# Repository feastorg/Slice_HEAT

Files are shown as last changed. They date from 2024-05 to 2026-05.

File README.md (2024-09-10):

# DC heating Element Controller Slice

DC heating Element Controller Slice for BREAD.

## Introduction

[Short introduction on the project.]

## Usage

[Explain how to use the project. Include examples and screenshots if applicable.]

## Documentation

Please refer to the [docs](/docs) for more info.

---

<div align="center">
  <p>
    
    
  </p>
</div>

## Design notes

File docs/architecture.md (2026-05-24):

---
title: "Architecture"
description: "Hardware and firmware architecture overview."
---

# Architecture

## Hardware

Heater control slice with MAX31855K thermocouple interface for closed-loop temperature control.

## Firmware

Arduino-based heater control sketch (`HEAT.ino`).

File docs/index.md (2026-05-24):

---
title: "Slice HEAT Documentation"
description: "Overview and entry page for Slice HEAT project documentation."
nav_exclude: true
---

Welcome to the Slice HEAT project documentation.

## Board Renders

<figure style="display:inline-block; text-align:center; margin:10px;">
  Board Top
  <figcaption>Top</figcaption>
</figure>

<figure style="display:inline-block; text-align:center; margin:10px;">
  Board Bottom
  <figcaption>Bottom</figcaption>
</figure>

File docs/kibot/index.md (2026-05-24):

---
title: "KiBot Outputs"
description: "Index for KiBot-generated PCB artifacts."
layout: "page"
---

These are the docs & KiBot Outputs for Slice HEAT

The following files were generated from the latest PCB build:

_(Not yet generated — will be populated by CI on first successful run.)_

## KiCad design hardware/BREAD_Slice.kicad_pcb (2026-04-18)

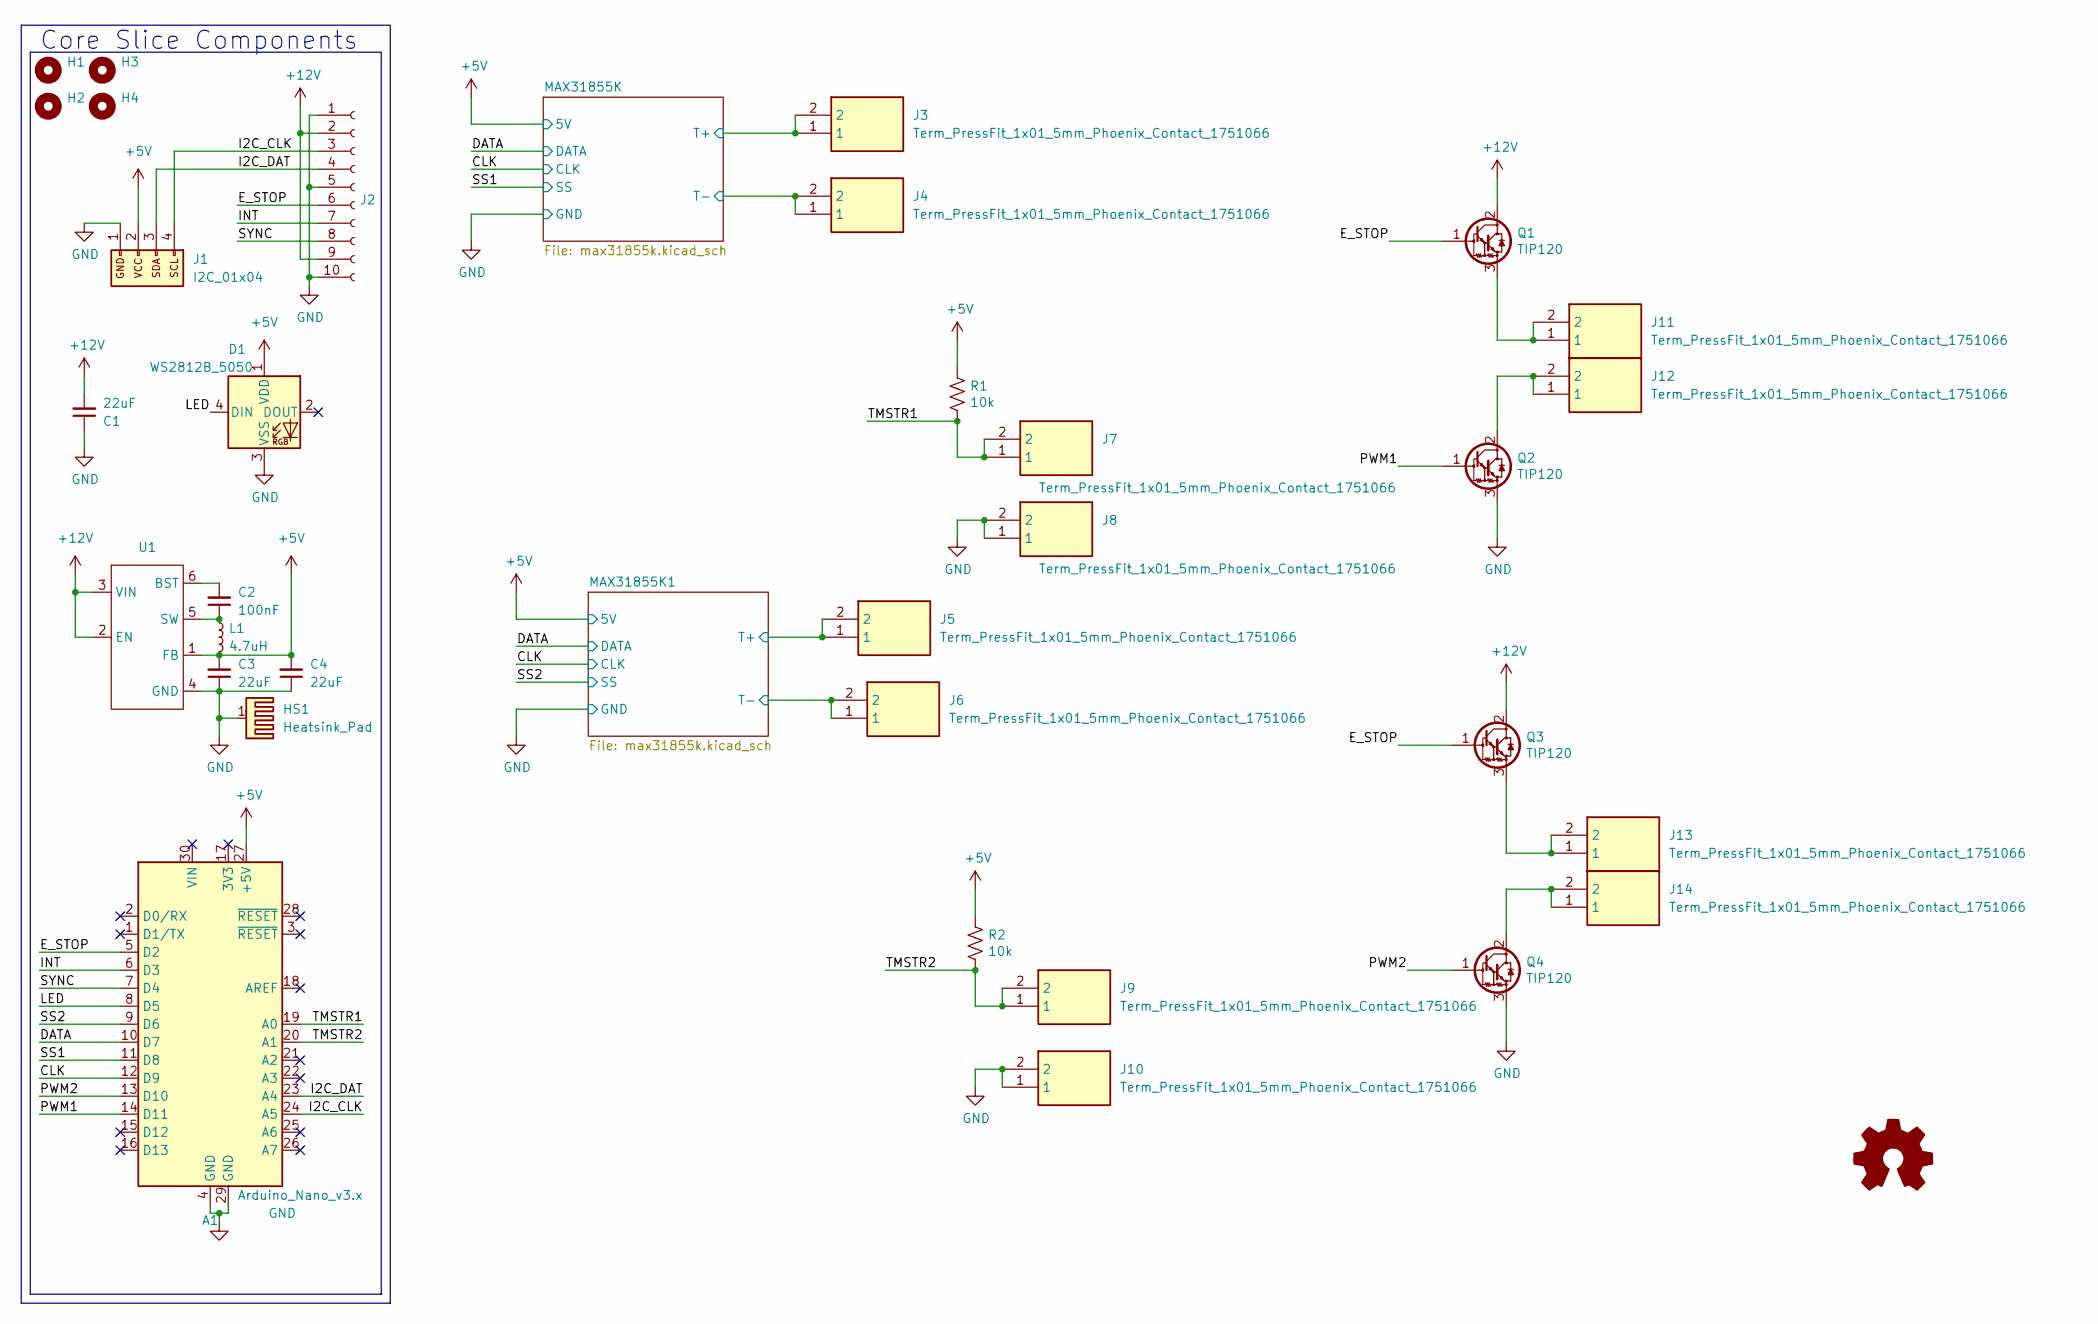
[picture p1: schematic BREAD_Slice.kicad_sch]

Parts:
A1: Arduino_Nano_v3.x; Arduino_Nano
C1, C3, C4: 22uF; C_1206_3216Metric
C2: 100nF; C_1206_3216Metric
D1: WS2812B_5050; WS2812-5050-4PIN
H1, H2, H3, H4: MountingHole; MountingHole_5mm
HS1: Heatsink_Pad; Thermal Pad
J1: I2C_01x04; JST_SH_SM04B-SRSS-TB_1x04-1MP_P1.00mm_Horizontal
J2: Conn_01x10_Female; PinSocket_1x10_P2.54mm_Horizontal
J3, J4, J5, J6, J7, J8, J9, J10, J11, J12, J13, J14: Term_PressFit_1x01_5mm_Phoenix_Contact_1751066; 1751066; Manufacturer_Part_Number 1751066
L1: 4.7uH; L_1210_3225Metric
Q1, Q2: TIP120; TO-220-3_Horizontal_TabDown
Q3, Q4: TIP120; TO-220-3_Horizontal_TabUp
R1, R2: 10k; R_1206_3216Metric_Pad1.30x1.75mm_HandSolder
U1: TSOT-23-6

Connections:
+5V: A1.27 (+5V), C3.2, C4.2, D1.1 (VDD), J1.2, L1.2, R1.1, R2.1, U1.1 (FB); also elsewhere on the board
+12V: C1.2, J2.2, J2.9, Q1.2 (C), Q3.2 (C), U1.2 (EN), U1.3 (VIN)
/CLK: A1.12 (D9); also elsewhere on the board
/DATA: A1.10 (D7); also elsewhere on the board
/E_STOP: A1.5 (D2), J2.6, Q1.1 (B), Q3.1 (B)
/I2C_CLK: A1.24 (A5), J1.4, J2.3
/I2C_DAT: A1.23 (A4), J1.3, J2.4
/INT: A1.6 (D3), J2.7
/LED: A1.8 (D5), D1.4 (DIN)
/MAX31855K1/T+: J5.1, J5.2; also elsewhere on the board
/MAX31855K1/T-: J6.1, J6.2; also elsewhere on the board
/MAX31855K/T+: J3.1, J3.2; also elsewhere on the board
/MAX31855K/T-: J4.1, J4.2; also elsewhere on the board
/PWM1: A1.14 (D11), Q2.1 (B)
/PWM2: A1.13 (D10), Q4.1 (B)
/SS1: A1.11 (D8); also elsewhere on the board
/SS2: A1.9 (D6); also elsewhere on the board
/SYNC: A1.7 (D4), J2.8
/TMSTR1: A1.19 (A0), J7.1, J7.2, R1.2
/TMSTR2: A1.20 (A1), J9.1, J9.2, R2.2
GND: A1.4 (GND), A1.29 (GND), C1.1, C3.1, C4.1, D1.3 (VSS), HS1.1, J1.1, J2.1, J2.5, J2.10, J8.1, J8.2, J10.1, J10.2, Q2.3 (E), Q4.3 (E), U1.4 (GND); also elsewhere on the board
unnamed: J11.1, J11.2, Q1.3 (E)
unnamed: J12.1, J12.2, Q2.2 (C)
unnamed: J13.1, J13.2, Q3.3 (E)
unnamed: J14.1, J14.2, Q4.2 (C)
unnamed: C2.2, U1.6 (BST)
unnamed: C2.1, L1.1, U1.5 (SW)

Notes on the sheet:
Core Slice Components

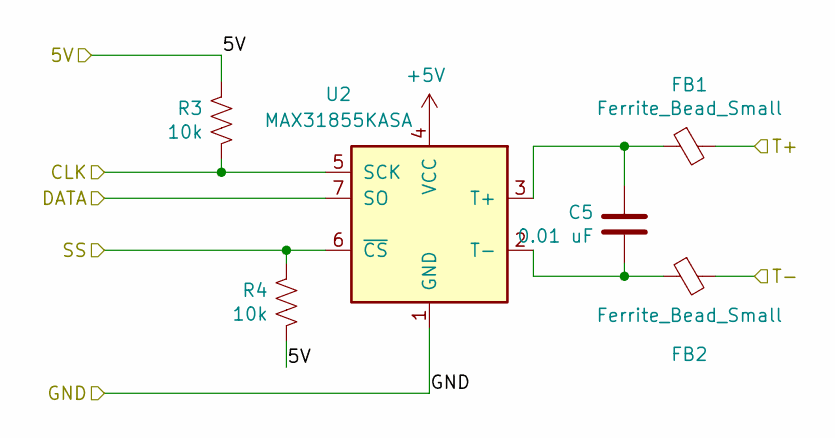
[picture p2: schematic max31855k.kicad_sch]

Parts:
C5: 0.01 uF; C_1206_3216Metric_Pad1.33x1.80mm_HandSolder
FB1, FB2: Ferrite_Bead_Small; R_1206_3216Metric_Pad1.30x1.75mm_HandSolder
R3, R4: 10k; R_1206_3216Metric_Pad1.30x1.75mm_HandSolder
U2: MAX31855KASA; SOIC-8_3.9x4.9mm_P1.27mm

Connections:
+5V: R3.1, R4.2, U2.4 (VCC); also elsewhere on the board
/CLK: R3.2, U2.5 (SCK); also elsewhere on the board
/DATA: U2.7 (SO); also elsewhere on the board
/MAX31855K/T+: FB1.2; also elsewhere on the board
/MAX31855K/T-: FB2.2; also elsewhere on the board
/SS1: R4.1, U2.6 (~CS); also elsewhere on the board
GND: U2.1 (GND); also elsewhere on the board
unnamed: C5.1, FB1.1, U2.3 (T+)
unnamed: C5.2, FB2.1, U2.2 (T-)

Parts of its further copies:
C6: 0.01 uF; C_1206_3216Metric_Pad1.33x1.80mm_HandSolder
FB3, FB4: Ferrite_Bead_Small; R_1206_3216Metric_Pad1.30x1.75mm_HandSolder
R5, R6: 10k; R_1206_3216Metric_Pad1.30x1.75mm_HandSolder
U3: MAX31855KASA; SOIC-8_3.9x4.9mm_P1.27mm

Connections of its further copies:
+5V: R5.1, R6.2, U3.4 (VCC); also elsewhere on the board
/CLK: R5.2, U3.5 (SCK); also elsewhere on the board
/DATA: U3.7 (SO); also elsewhere on the board
/MAX31855K1/T+: FB3.2; also elsewhere on the board
/MAX31855K1/T-: FB4.2; also elsewhere on the board
/SS2: R6.1, U3.6 (~CS); also elsewhere on the board
GND: U3.1 (GND); also elsewhere on the board
unnamed: C6.1, FB3.1, U3.3 (T+)
unnamed: C6.2, FB4.1, U3.2 (T-)

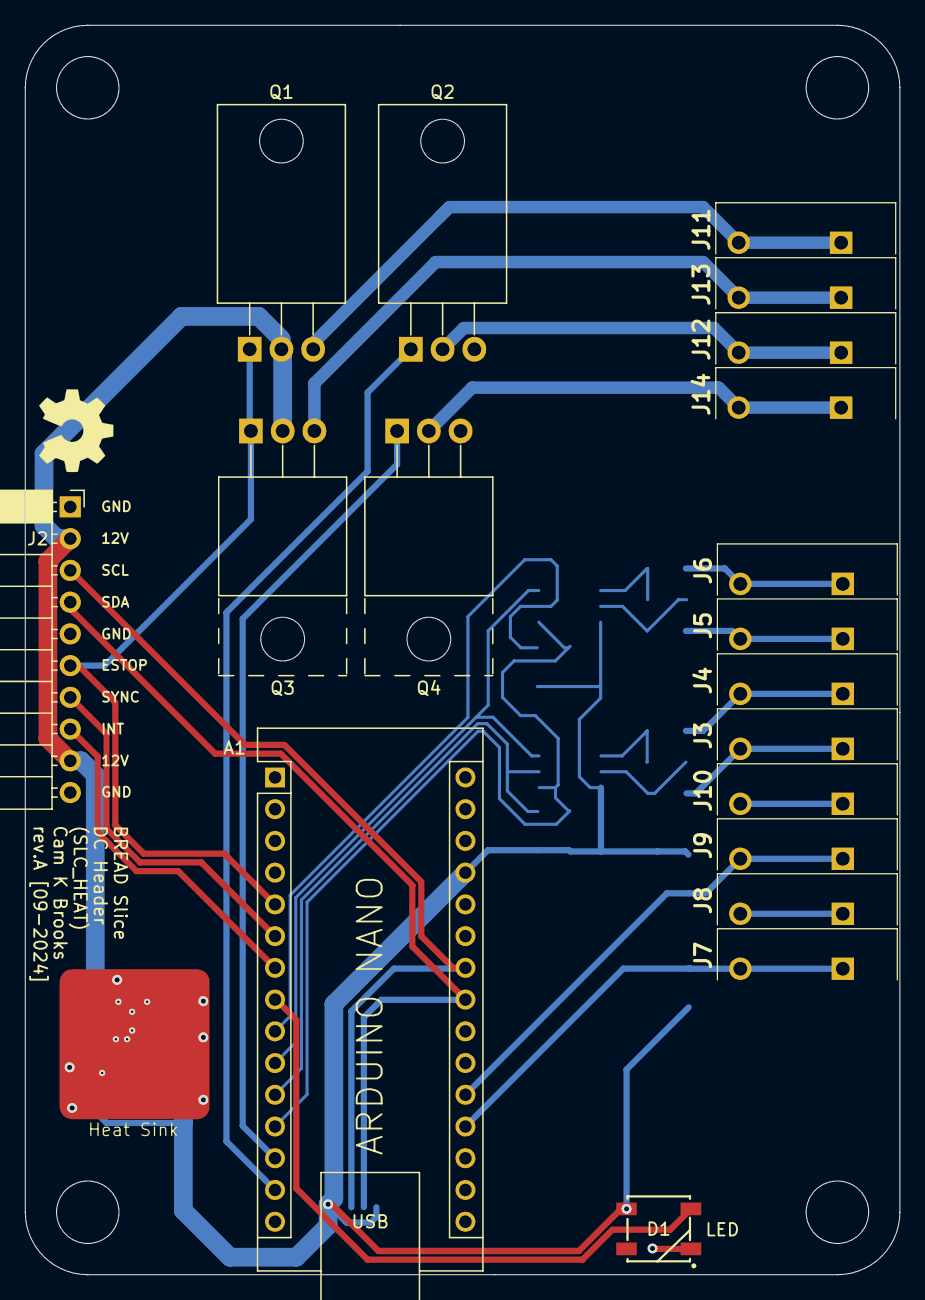
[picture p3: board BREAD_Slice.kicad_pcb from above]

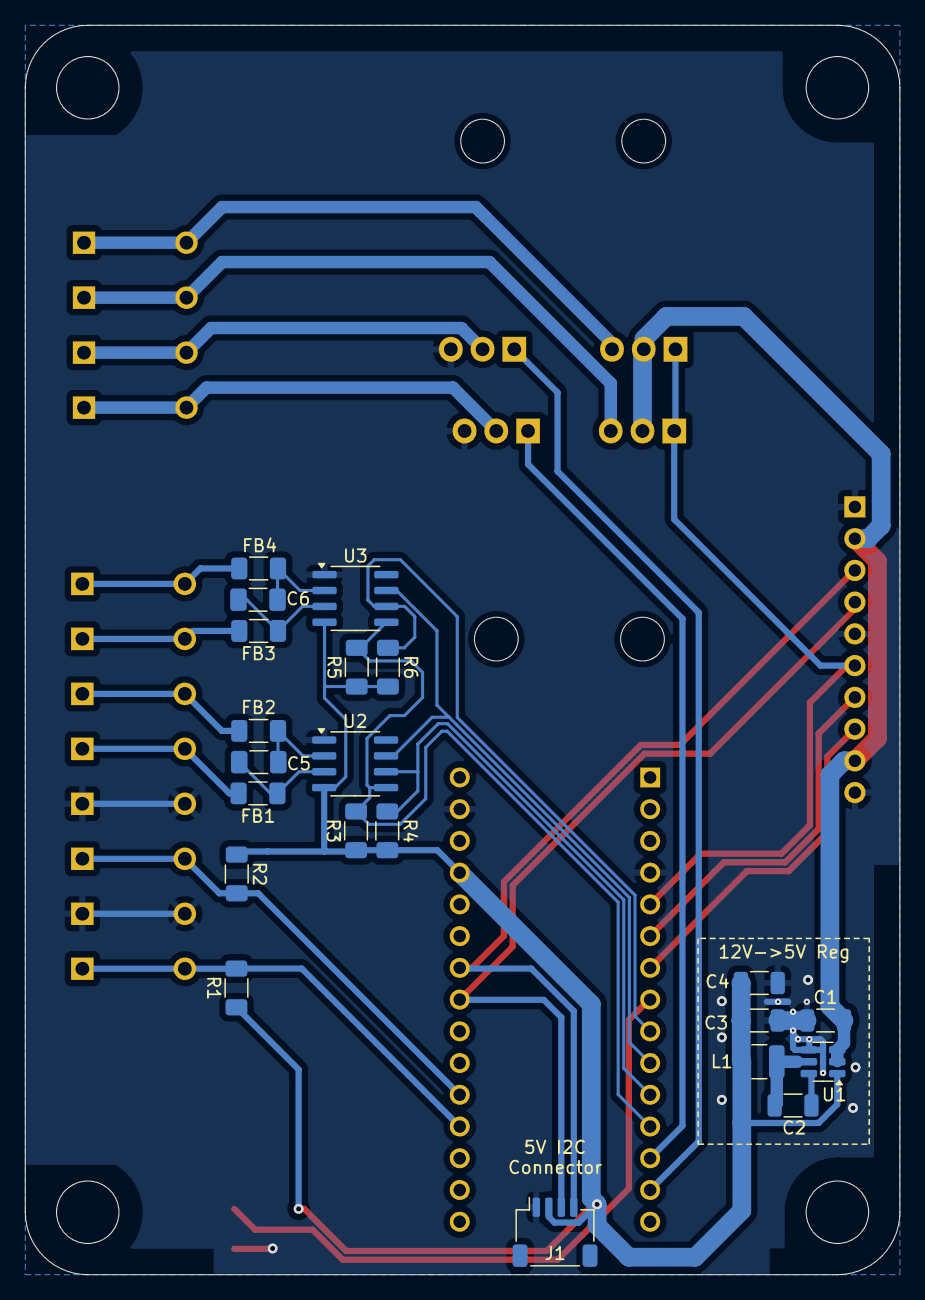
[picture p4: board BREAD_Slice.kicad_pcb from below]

Board: 2 copper layers, 70.0 x 100.0 mm, 46 parts (21 on the bottom side), 31 nets.

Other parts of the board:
Logo1: Logo_Open_Hardware_Small; OSHW-Symbol_6.7x6mm_SilkScreen

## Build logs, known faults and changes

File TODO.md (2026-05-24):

# Slice_HEAT TODO

## CI Results (Pass 1)

- [x] ERC (standalone): PASS
- [x] DRC: FAIL — blocked by ERC preflight: 2x power_pin_not_driven (input power pin not driven by output power pins)
- [x] Fab: FAIL — blocked by same ERC preflight errors
- [ ] gen-kibot-index: SKIPPED (upstream failed)
- [ ] deploy-pages: SKIPPED (upstream failed)

## Pass 2 – Pre-fab Review

- [ ] Fix 2x power_pin_not_driven ERC errors
- [ ] Verify BOM completeness
- [ ] Confirm board outline and mounting holes
- [ ] Update README.md (still says "Slice Template")

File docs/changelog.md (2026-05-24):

---
title: "Changelog"
description: "Hardware and firmware revision history."
---

# Changelog

## Hardware

### v0.1.0 (initial)
- Initial schematic and PCB layout
- MAX31855K thermocouple interface sub-circuit

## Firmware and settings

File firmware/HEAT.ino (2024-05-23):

#include <Wire.h>
#define I2C_ADR 6
#define MAXTEMP 100

typedef union //Define a float that can be broken up and sent via I2C
{
 float number;
 uint8_t bytes[4];
} FLOATUNION_t;

FLOATUNION_t RX_P1;
FLOATUNION_t RX_P2;

#include <PID_v1.h>
#include <SPI.h>
#include "Adafruit_MAX31855.h"

#define PIN_OUTPUT 6

//Thermocouple IO Pins
#define MAXDO   10
#define MAXCS   9
#define MAXCLK  11

// initialize the Thermocouple
Adafruit_MAX31855 thermocouple(MAXCLK, MAXCS, MAXDO);

//Define Variables we'll be connecting to
double Setpoint, Input, Output;
double Ramprate,Target,Setpoint_O;
boolean Rising; //1 Means temp rising


String inputString = "";         // a String to hold incoming data
boolean stringComplete = false;  // whether the string is complete

//Specify the links and initial tuning parameters
// Tune these a bit more precisely later
double Kp=50, Ki=1, Kd=.5;
PID myPID(&Input, &Output, &Setpoint, Kp, Ki, Kd, DIRECT);



void setup() {
  // put your setup code here, to run once:
  Wire.begin(I2C_ADR);                // join i2c bus with address #8
  Wire.onReceive(receiveEvent); // register event
  Wire.onRequest(requestEvent); // register event

  //initialize the variables we're linked to
  Input = thermocouple.readCelsius();
  Setpoint = 0;

  //turn the PID on
  myPID.SetMode(AUTOMATIC);

  inputString.reserve(50);

    Serial.begin(115200);
 
  while (!Serial) delay(1); // wait for Serial on Leonardo/Zero, etc
  delay(500);

  /////////////ONLY WHEN STAND-ALONE////////////////
  pinMode(2,OUTPUT);
  digitalWrite(2,HIGH); //manually writes E-Stop high
  //////////////////////////////////////////////////
}

void loop() {
  static unsigned long lastRefreshTime = 0;
  if(millis() - lastRefreshTime >= 1000)
  {
    if (Setpoint != Target)
    {
      double Step = Ramprate/60;
      if (Rising)
      {
        Setpoint+=Step;
        if (Setpoint > Target)
          Setpoint = Target;
      }
      else
      {
        Setpoint-=Step;
        if (Setpoint < Target)
          Setpoint = Target;
      }
    }
     Serial.print(Setpoint); 
     Serial.print(",");
     Serial.print(Target); 
     Serial.print(",");
     Serial.print(Input);
     Serial.print(",");
     Serial.println(Output*100/255);
    
    lastRefreshTime += 1000;
  }
     if (!measureThermocouple() || Input > MAXTEMP ) {
     Serial.println("Something wrong with thermocouple!");
     //If Feedback is broken - drive PID to cool.
     Setpoint = 0;
     Target = 0;
   }

  myPID.Compute();
  analogWrite(PIN_OUTPUT, Output);

    if (stringComplete) {
    // clear the string:
    inputString = "";
    stringComplete = false;
  }
}

// function that executes whenever data is received from master
// this function is registered as an event, see setup()
void receiveEvent(int howMany) {
  RX_P1.number = 0; RX_P2.number = 0;
  int ByteCount = 0;
  while (1 <= Wire.available()) { // loop through all but the last
    if (ByteCount <= 3)
    {
      RX_P1.bytes[ByteCount] = Wire.read(); // receive a byte as character
    }
    else
    {
      RX_P2.bytes[ByteCount-4] = Wire.read(); // receive a byte as character
    }
    ByteCount++;
  }
  stringComplete = true;
  Target = RX_P1.number;
  Ramprate = RX_P2.number;
  if (Target >= Setpoint)
    Rising = 1;
  if (Target < Setpoint)
    Rising = 0;

  digitalWrite(8,HIGH);
}

  #define maxErrs 3
bool thermocoupleIsConnected()
{
  static int numErrs = 0;
  if (isnan(Input))
  {
    numErrs++;
  }
  else
  {
    numErrs = 0;
  }
  if (numErrs >= maxErrs)
    return false;
  else
    return true;
}

void requestEvent() {
  RX_P1.number = Input;
  RX_P2.number = Setpoint;
  //Send both parameters
  for (int i = 0; i <=3; i++)
  {
    Wire.write(RX_P1.bytes[i]);
        //Serial.println(RX_P1.bytes[i]);
  }
  for (int i = 0; i <=3; i++)
  {
    Wire.write(RX_P2.bytes[i]);
    //Serial.println(RX_P2.bytes[i]);
  }
  digitalWrite(8,LOW);
}

bool measureThermocouple()
{
 double PreviousInput = Input;
  Input = thermocouple.readCelsius();
  
    static int numErrs = 0;
  if (isnan(Input))
  {
    numErrs++;
    Input = PreviousInput;
  }
  else
  {
    numErrs = 0;
  }
  if (numErrs >= maxErrs)
  {
    Input = 0;
    return false;
  }
  else
    return true;
}

void serialEvent() {
  while (Serial.available()) {
    // get the new byte:
    char inChar = (char)Serial.read();
    // add it to the inputString:
    inputString += inChar;
    // if the incoming character is a newline, set a flag so the main loop can
    // do something about it:
    if (inChar == '\n') {
      stringComplete = true;
      Target = inputString.substring(0, inputString.indexOf(',')).toDouble();
      Ramprate = inputString.substring(inputString.indexOf(',')+1).toDouble();
      if (Target >= Setpoint)
        Rising = 1;
      if (Target < Setpoint)
        Rising = 0;
    }
  }
}

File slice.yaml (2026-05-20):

schema_version: "1.0"

# ── Identity ──────────────────────────────────────────────────────────────────
id: "slice-heat"
name: "DC Heating Element Controller"
status: "prototype"
category: "integrated"

summary: "DC heating element controller with thermocouple feedback and PID."
description: null

# ── Versioning ────────────────────────────────────────────────────────────────
version:
  hardware: "0.1.0"
  firmware: "0.1.0"
  manifest: "0.1.0"

# ── Compatibility ─────────────────────────────────────────────────────────────
compatibility:
  slice_spec: ">=0.1.0 <0.2.0"
  crumbs_protocol: null
  anolis_provider_api: null

# ── Hardware ──────────────────────────────────────────────────────────────────
hardware:
  mcu:
    type: "dev-board-socket"
    form_factor: "nano"
    primary: "ATmega328P"
    supported:
      - "ATmega328P"
  primary_ic:
    manufacturer: "Analog Devices"
    part_number: "MAX31855K"
  hw_gen_current: 1
  hw_gen_supported: [1]
  pcb:
    layers: 2
    thickness: "1.6mm"
    copper_weight: "1oz"
    dimensions: "70mm x 100mm"
  connectors:
    - ref: "J1"
      type: "slice-bus-10pin"
      purpose: "power-and-i2c"
  mounting:
    pattern: "slice-standard-v0"
    hole_size: "M3"
    inset: "5mm"
  pcb_color_prototype: null
  pcb_color_production: null
  enclosure:
    supported: false
    path: null

# ── Electrical ────────────────────────────────────────────────────────────────
electrical:
  input_voltage: "12V"
  logic_voltage: "5V"
  max_current: null
  protection:
    reverse_polarity: false
    input_esd: false
    fuse: false
  isolation:
    present: false

# ── Interfaces ────────────────────────────────────────────────────────────────
interfaces:
  host:
    type: "i2c"
    address_default: 6
    address_configurable: true
  data:
    inputs:
      - name: "TC1"
        type: "thermocouple-k"
    outputs:
      - name: "HEATER1"
        type: "pwm-dc"

# ── Capabilities ──────────────────────────────────────────────────────────────
capabilities:
  - id: "temperature_sensing"
    channels: 1
    control_modes: []
  - id: "dc_heater_control"
    channels: 1
    control_modes: ["pid", "ramp"]

# ── Firmware ──────────────────────────────────────────────────────────────────
firmware:
  required: true
  path: "firmware/"
  language: "c++"
  framework: "arduino"
  targets:
    - "nano"
  lib_deps:
    - "PID_v1"
    - "Adafruit_MAX31855"

# ── Protocol ──────────────────────────────────────────────────────────────────
protocol:
  type: "i2c-custom"
  discovery:
    supported: false
  commands: []

# ── Software ──────────────────────────────────────────────────────────────────
software: null

# ── Artifacts ─────────────────────────────────────────────────────────────────
artifacts:
  schematic: "hardware/BREAD_Slice.kicad_sch"
  pcb: "hardware/BREAD_Slice.kicad_pcb"
  firmware: "firmware/"
  docs: null
  bom: "documentation/BOM_TEMP.ods"
  gerbers: "hardware/Gerbers/"
  pick_and_place: null
  datasheets: []

# ── Manufacturing ─────────────────────────────────────────────────────────────
manufacturing:
  assembly_type: "manual"
  preferred_fab: null
  dnp_parts: []
  critical_parts: []
  substitutions_allowed: true

# ── Validation ────────────────────────────────────────────────────────────────
validation:
  status: "not_validated"
  tested_revisions: []
  tests:
    electrical: false
    firmware: false
    environmental: false
    integration: false
  known_issues: []

# ── Safety ────────────────────────────────────────────────────────────────────
safety:
  hazards:
    - "high-temperature surfaces"
  max_safe_voltage: "12V"
  intended_environment: "lab"
  not_for:
    - "human safety critical systems"
    - "unattended heating operations"

# ── Dependencies ──────────────────────────────────────────────────────────────
dependencies:
  hardware: []
  firmware_libraries: []
  software_packages: []

# ── Relations ─────────────────────────────────────────────────────────────────
related:
  supersedes: null
  superseded_by: null
  variants: []
  compatible_slices: ["slice-rlht"]

# ── Maintainers ───────────────────────────────────────────────────────────────
maintainers:
  - name: "Cameron Brooks"
    role: "owner"

# ── License ───────────────────────────────────────────────────────────────────
license:
  hardware: "CERN-OHL-S-2.0"
  firmware: "GPL-3.0-or-later"
  software: null
  docs: "CC-BY-4.0"

# ── Repository ────────────────────────────────────────────────────────────────
repository:
  url: "https://github.com/feastorg/Slice_HEAT"

# ── Metadata ──────────────────────────────────────────────────────────────────
metadata:
  created: "2026-05-19"
  updated: "2026-05-19"
  tags:
    - "heater-control"
    - "thermocouple"
    - "pid"
    - "temperature"
    - "dc-heating"

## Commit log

2024-09-10 upgraded by duplicating ciruit, new core, all back copper
    [BREAD_Slice-B_Cu.gbr, BREAD_Slice-B_Mask.gbr, BREAD_Slice-B_Paste.gbr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]
2024-09-10 removed old design
    [BREAD_Slice-B_Cu.gbr, BREAD_Slice-B_Mask.gbr, BREAD_Slice-B_Paste.gbr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]
2024-09-12 minor fixes
    [BREAD_Slice.kicad_pcb]
2024-09-12 updated to the correct terminals and proper hierarchial pages
    [BREAD_Slice.kicad_pcb, BREAD_Slice.kicad_sch, max31855k.kicad_sch]
2024-09-30 JLCPCB order rev-A
    [BREAD_Slice-B_Cu.gbr, BREAD_Slice-B_Mask.gbr, BREAD_Slice-B_Paste.gbr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]
2026-04-18 chore: minor updates
    [BREAD_Slice.kicad_sch, max31855k.kicad_sch]
2026-04-18 chore: update to kicad9
    [BREAD_Slice.kicad_pcb, BREAD_Slice.kicad_sch, max31855k.kicad_sch]
